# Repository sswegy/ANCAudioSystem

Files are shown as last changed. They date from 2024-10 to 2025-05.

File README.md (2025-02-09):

# ANCAudioSystem
## Автомобилна аудио система с активно шумопотискане - Дипломна работа

## Характеристики
- Активно шумопотискане
- Изравняване на звука по 3 честотни ленти
- Изравняване на противошума по 3 честотни ленти
- Bluetooth връзка
- AUX връзка
- Визуализация на метаданните на песните
- Контроли за промяна/пауза на песента

## Използвани технологии
- ESP32-WROOM-32
- C++
- Електроника

[Документация](https://docs.google.com/document/d/18OyuSNhzSNt5vsgb9MGb9Y_gkE6eRHnCl0IYLaxOIx8/edit?usp=sharing)

## Автор
[Виктор Велков](https://www.github.com/sswegy) 

Произведено во Света Троица

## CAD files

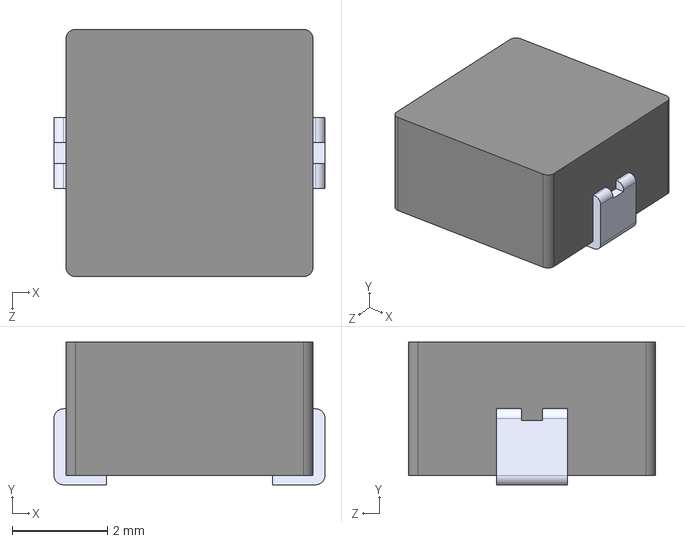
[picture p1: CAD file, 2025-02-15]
Electronics/KiCad_SnF_Library/3DModels/SRP5030T-1R0M.step
5.70 x 3.00 x 5.20 mm

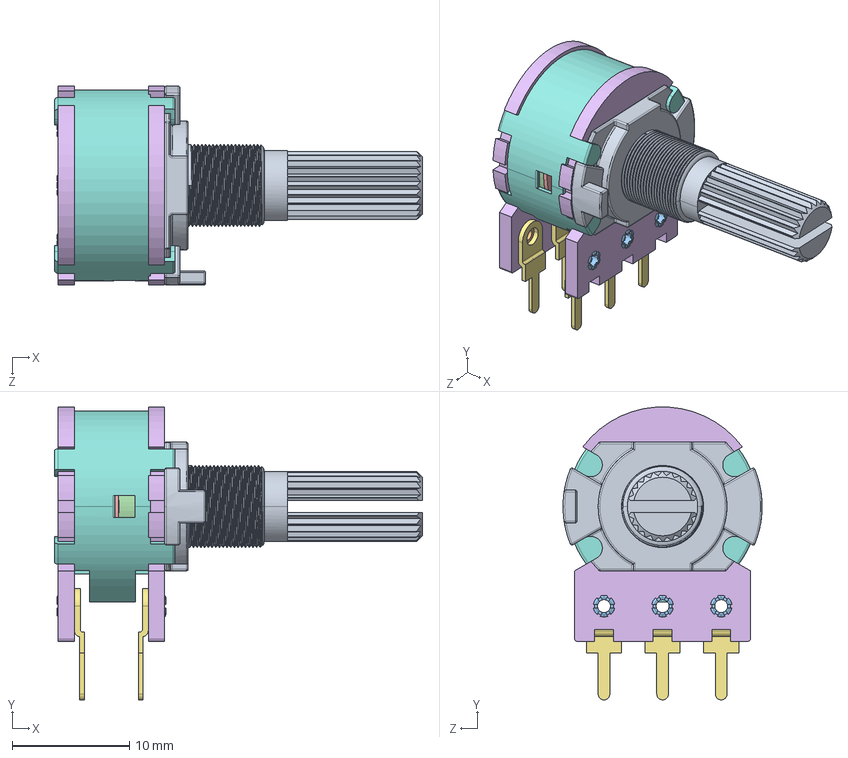
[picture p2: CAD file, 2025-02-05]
Electronics/KiCad_SnF_Library/3DModels/OtherPotentiometer.step
31.4 x 25.0 x 17.0 mm
PTN16_2 BUSHING
PTN16-A_2 HOUSING
PTN16_20K1_SHAFT

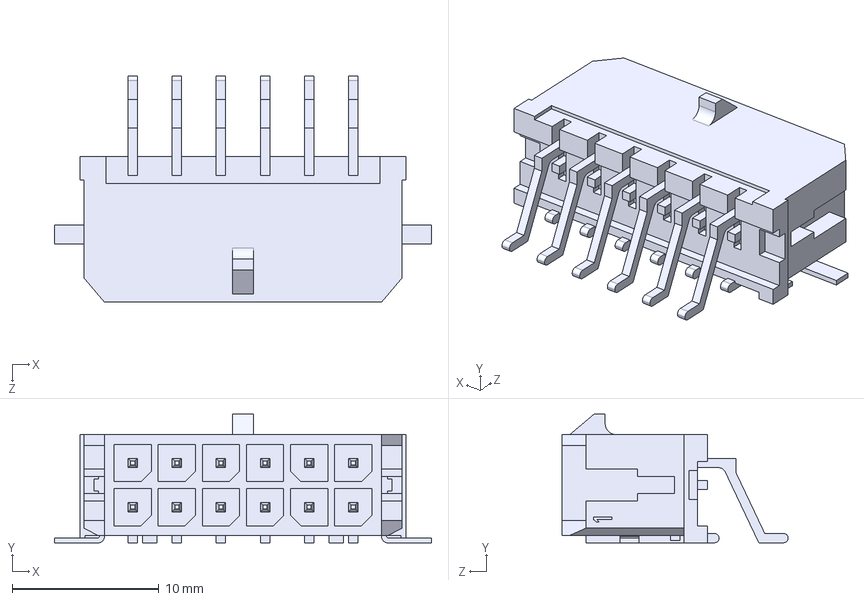
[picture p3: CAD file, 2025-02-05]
Electronics/KiCad_SnF_Library/3DModels/Molex-43045-1211.STEP
25.6 x 8.77 x 15.4 mm

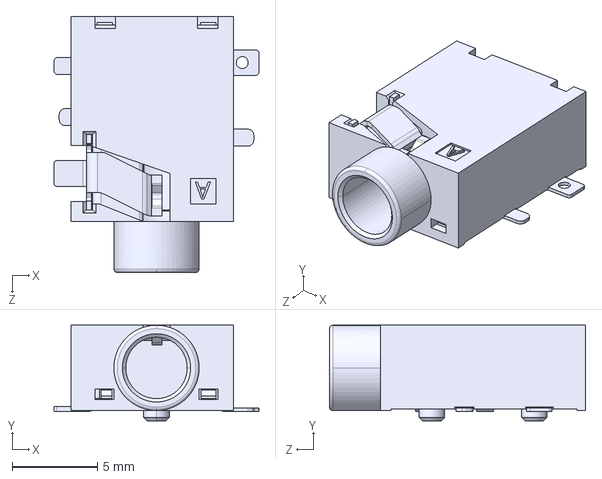
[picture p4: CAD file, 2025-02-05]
Electronics/KiCad_SnF_Library/3DModels/SJ1-3515-SMT-TR-BE.STEP
12.0 x 5.60 x 15.0 mm

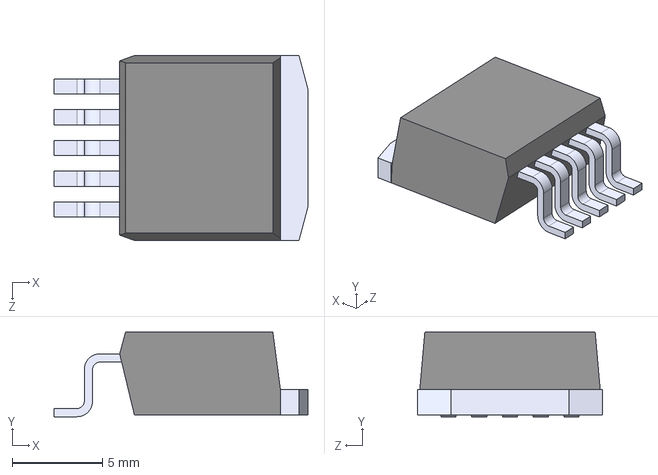
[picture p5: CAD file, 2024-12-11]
Electronics/KiCad_SnF_Library/3DModels/LT3015EQ-5PBF.step
14.0 x 4.67 x 10.2 mm

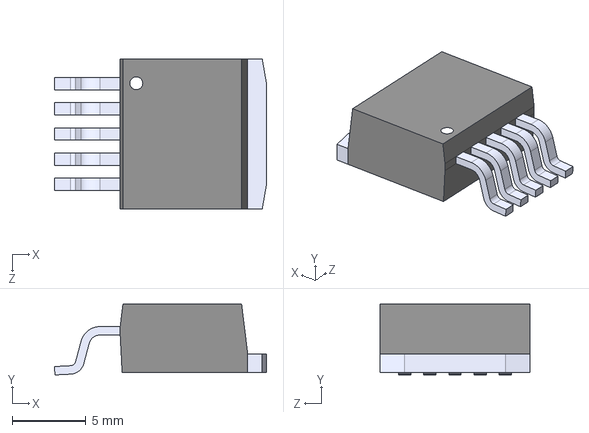
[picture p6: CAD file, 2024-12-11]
Electronics/KiCad_SnF_Library/3DModels/LP3856ES-5.0.step
14.4 x 4.80 x 10.2 mm

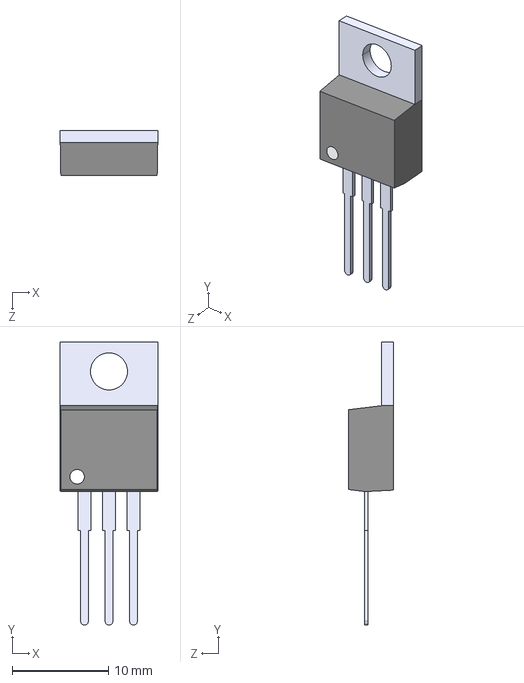
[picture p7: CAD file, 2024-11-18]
Electronics/KiCad_SnF_Library/3DModels/LM1085IT-3.3.step
10.2 x 29.3 x 4.70 mm

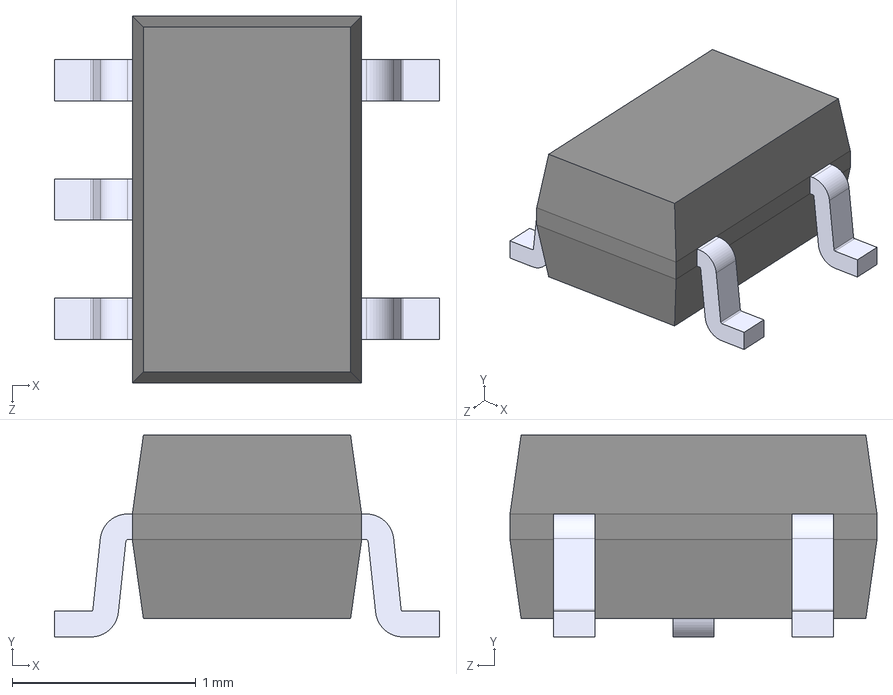
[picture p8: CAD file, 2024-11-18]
Electronics/KiCad_SnF_Library/3DModels/MIC5365-1.2YC5-TR.step
2.10 x 1.10 x 2.00 mm

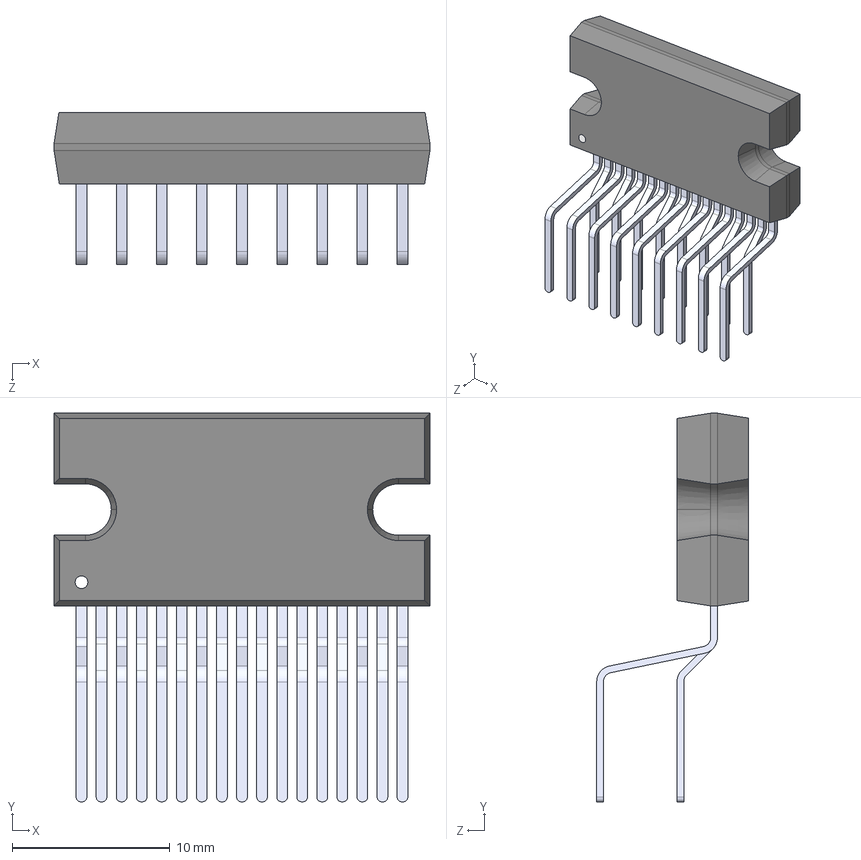
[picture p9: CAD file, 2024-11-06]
Electronics/KiCad_SnF_Library/3DModels/TDA1558Q.step
23.8 x 24.6 x 9.59 mm

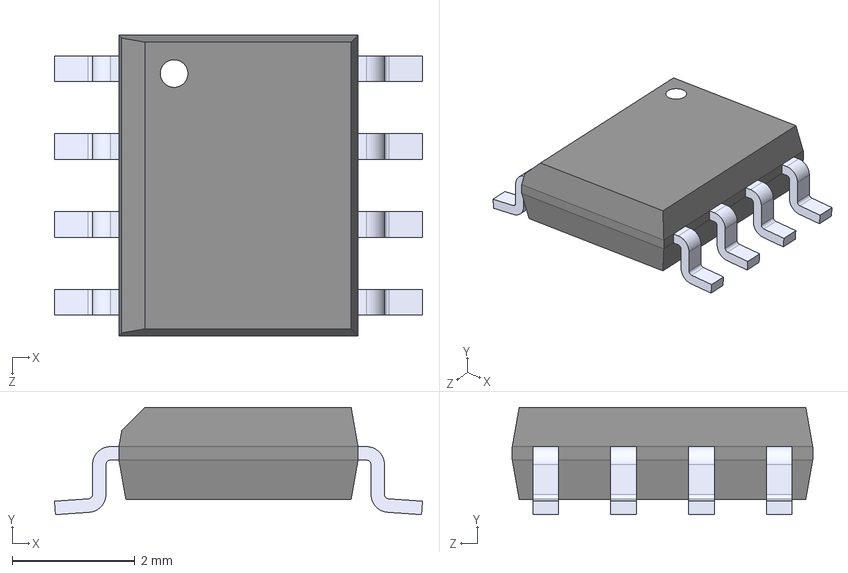
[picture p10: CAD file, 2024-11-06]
Electronics/KiCad_SnF_Library/3DModels/MAX660ESA.step
6.00 x 1.75 x 4.90 mm

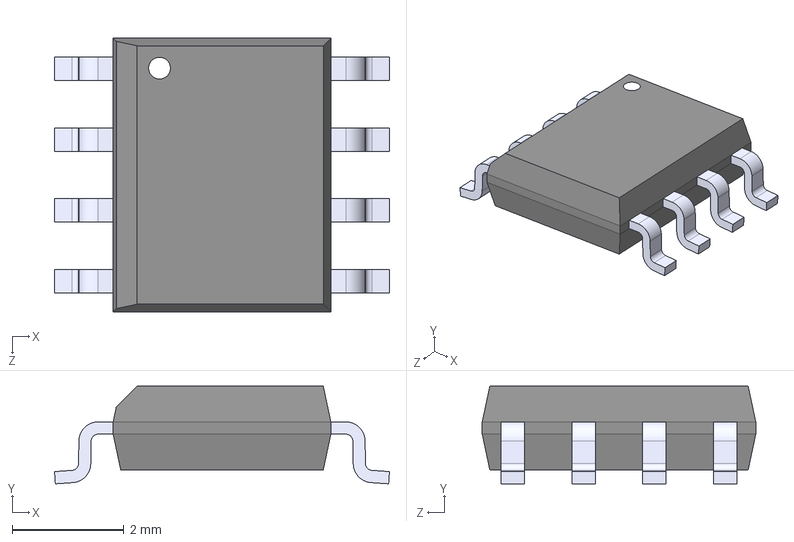
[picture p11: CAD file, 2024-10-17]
Electronics/KiCad_SnF_Library/3DModels/OPA2134UA.step
6.00 x 1.75 x 4.90 mm

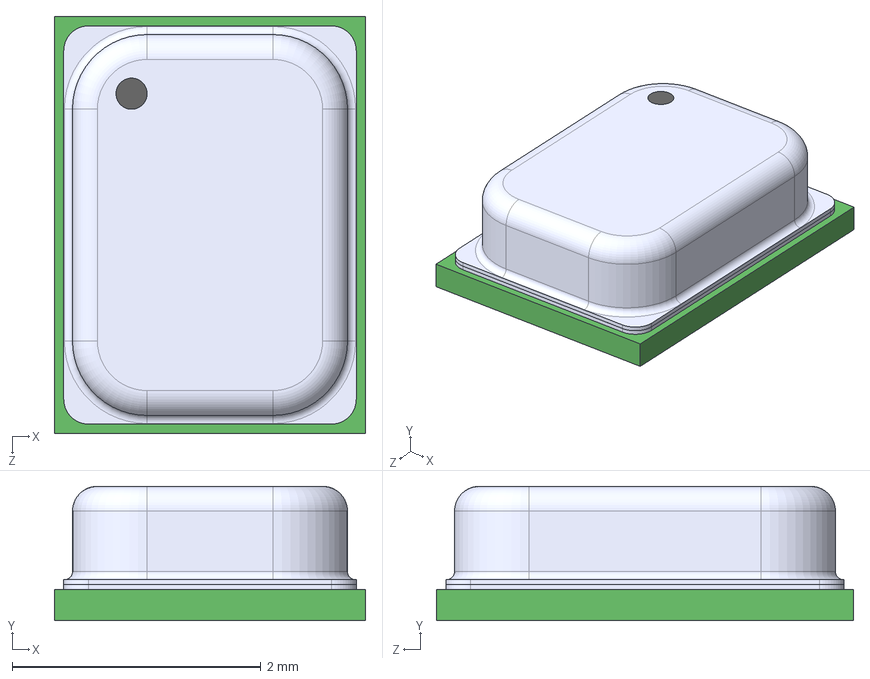
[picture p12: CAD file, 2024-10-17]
Electronics/KiCad_SnF_Library/3DModels/ICS-40310.step
2.50 x 1.08 x 3.35 mm

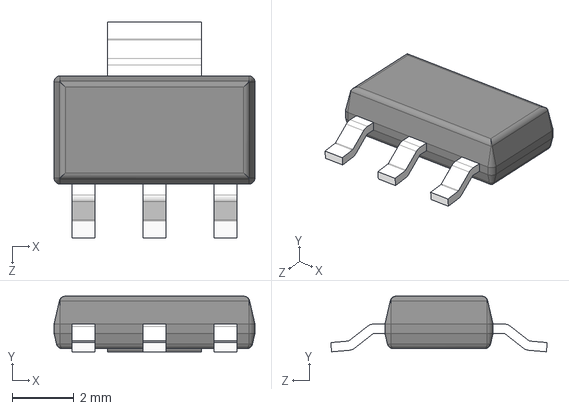
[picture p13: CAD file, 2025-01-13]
Electronics/KiCad_SnF_Library/3DModels/MIC39100-5.0WS.step
6.50 x 1.80 x 7.00 mm

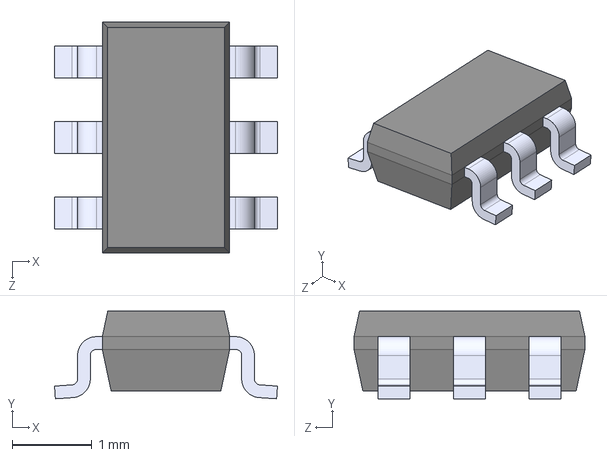
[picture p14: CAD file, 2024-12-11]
Electronics/KiCad_SnF_Library/3DModels/LMR51420XFDDCR.step
2.80 x 1.10 x 2.90 mm

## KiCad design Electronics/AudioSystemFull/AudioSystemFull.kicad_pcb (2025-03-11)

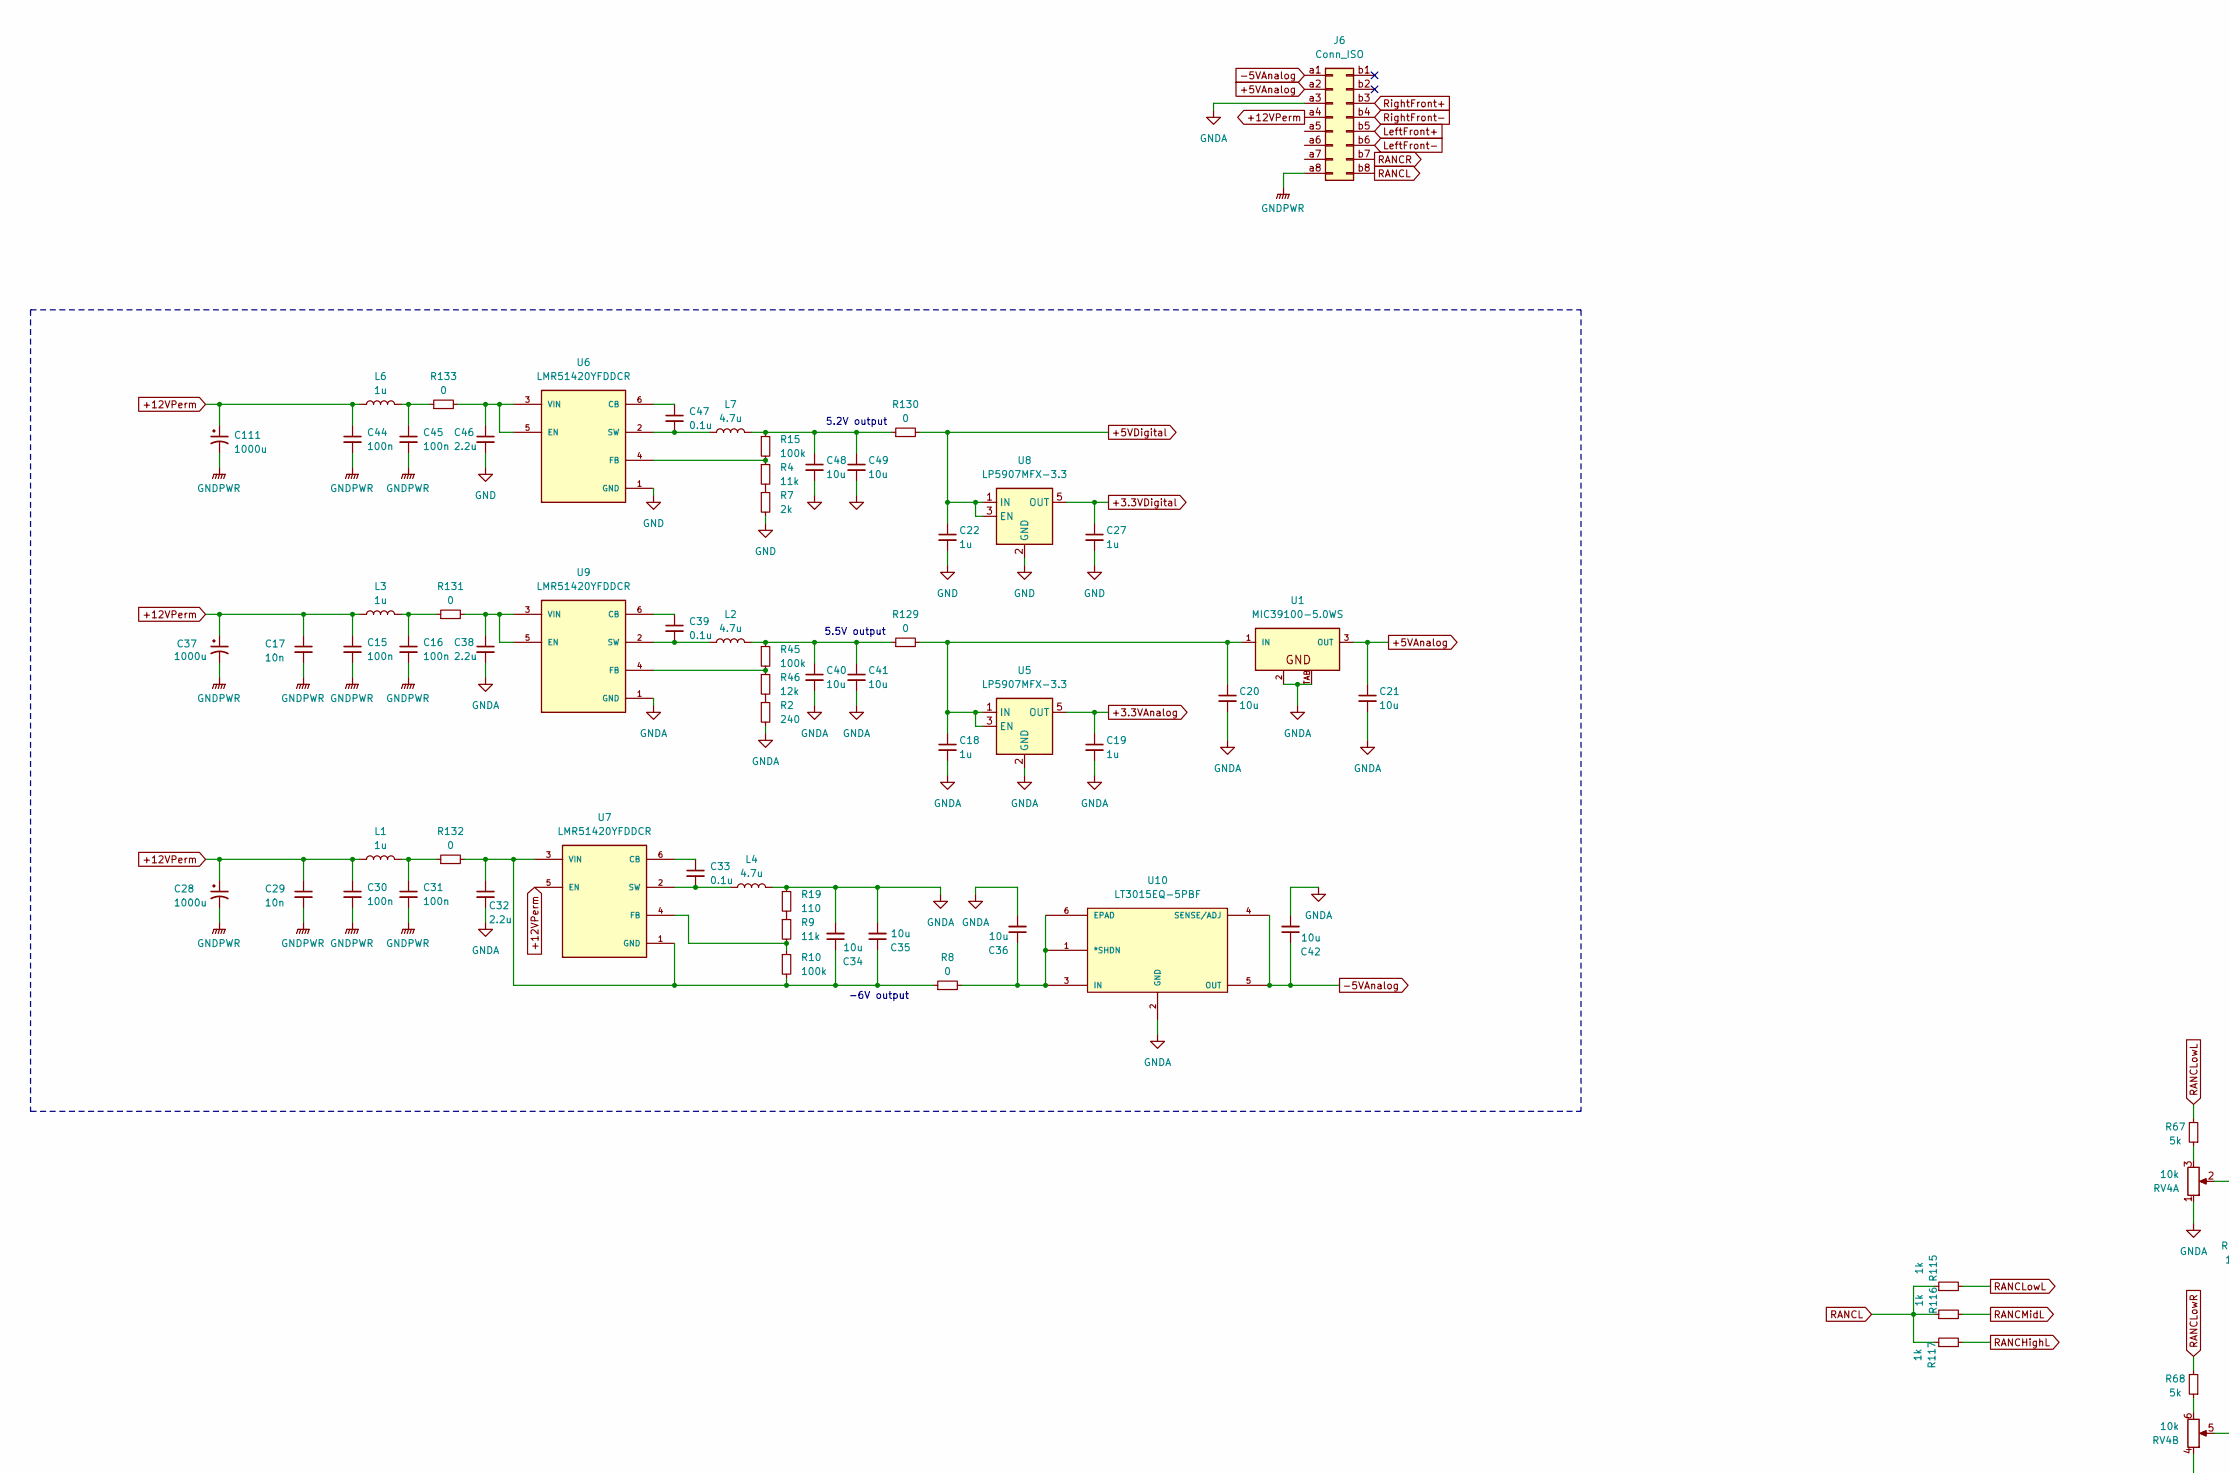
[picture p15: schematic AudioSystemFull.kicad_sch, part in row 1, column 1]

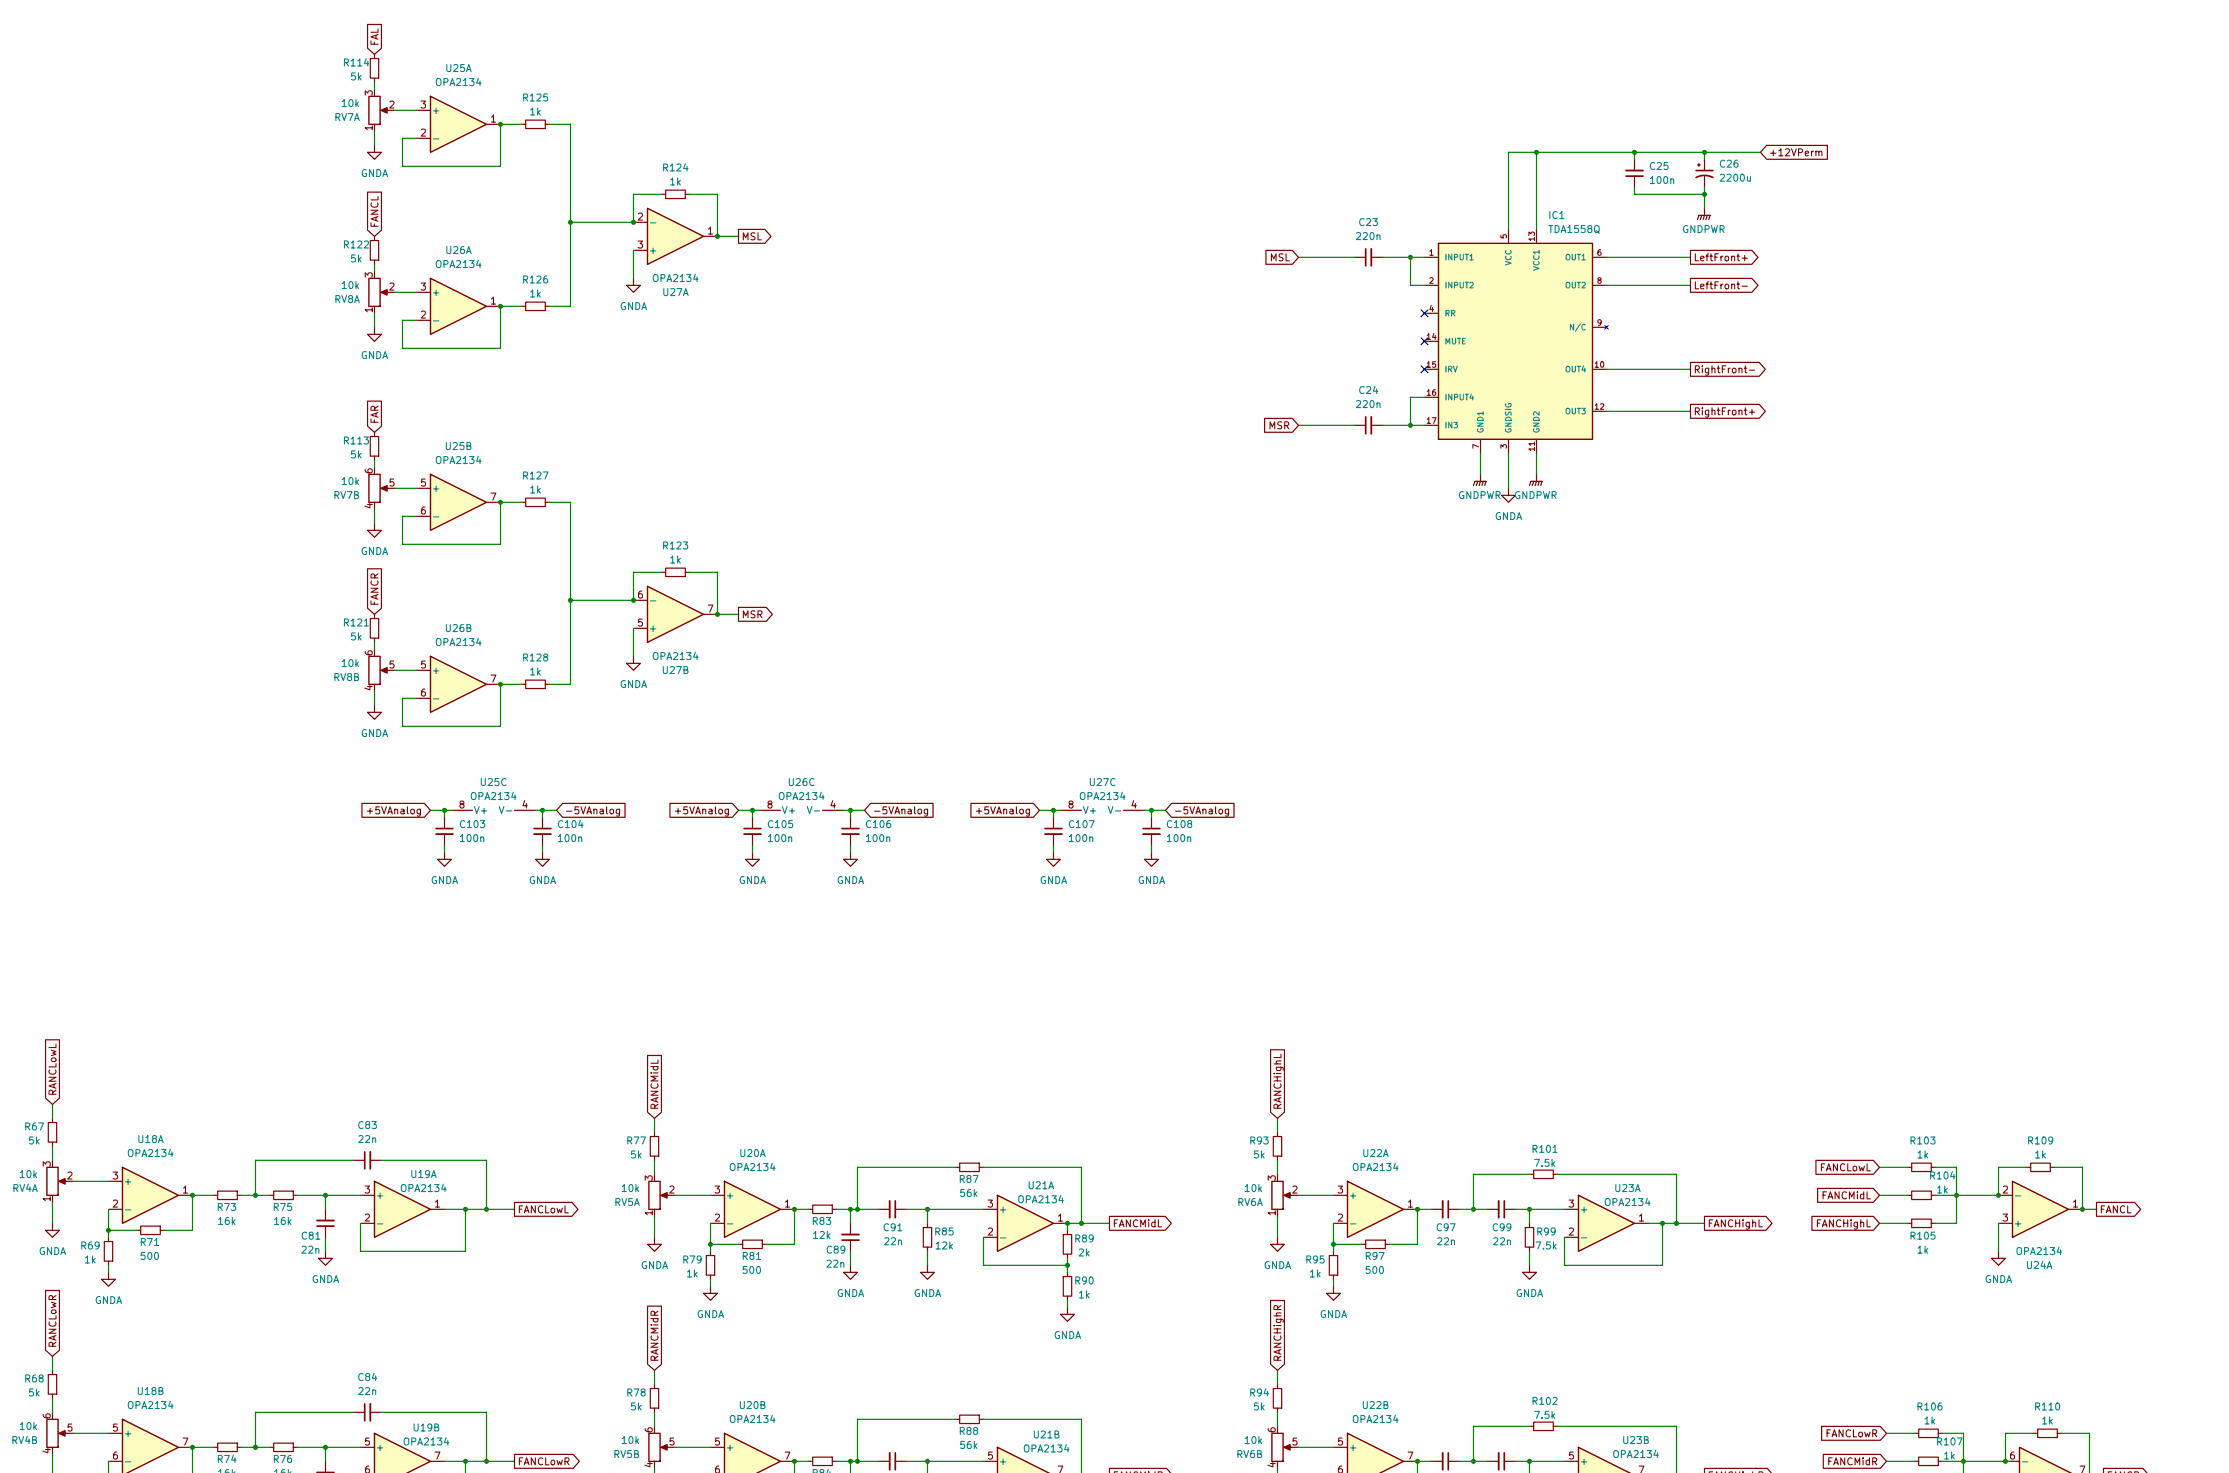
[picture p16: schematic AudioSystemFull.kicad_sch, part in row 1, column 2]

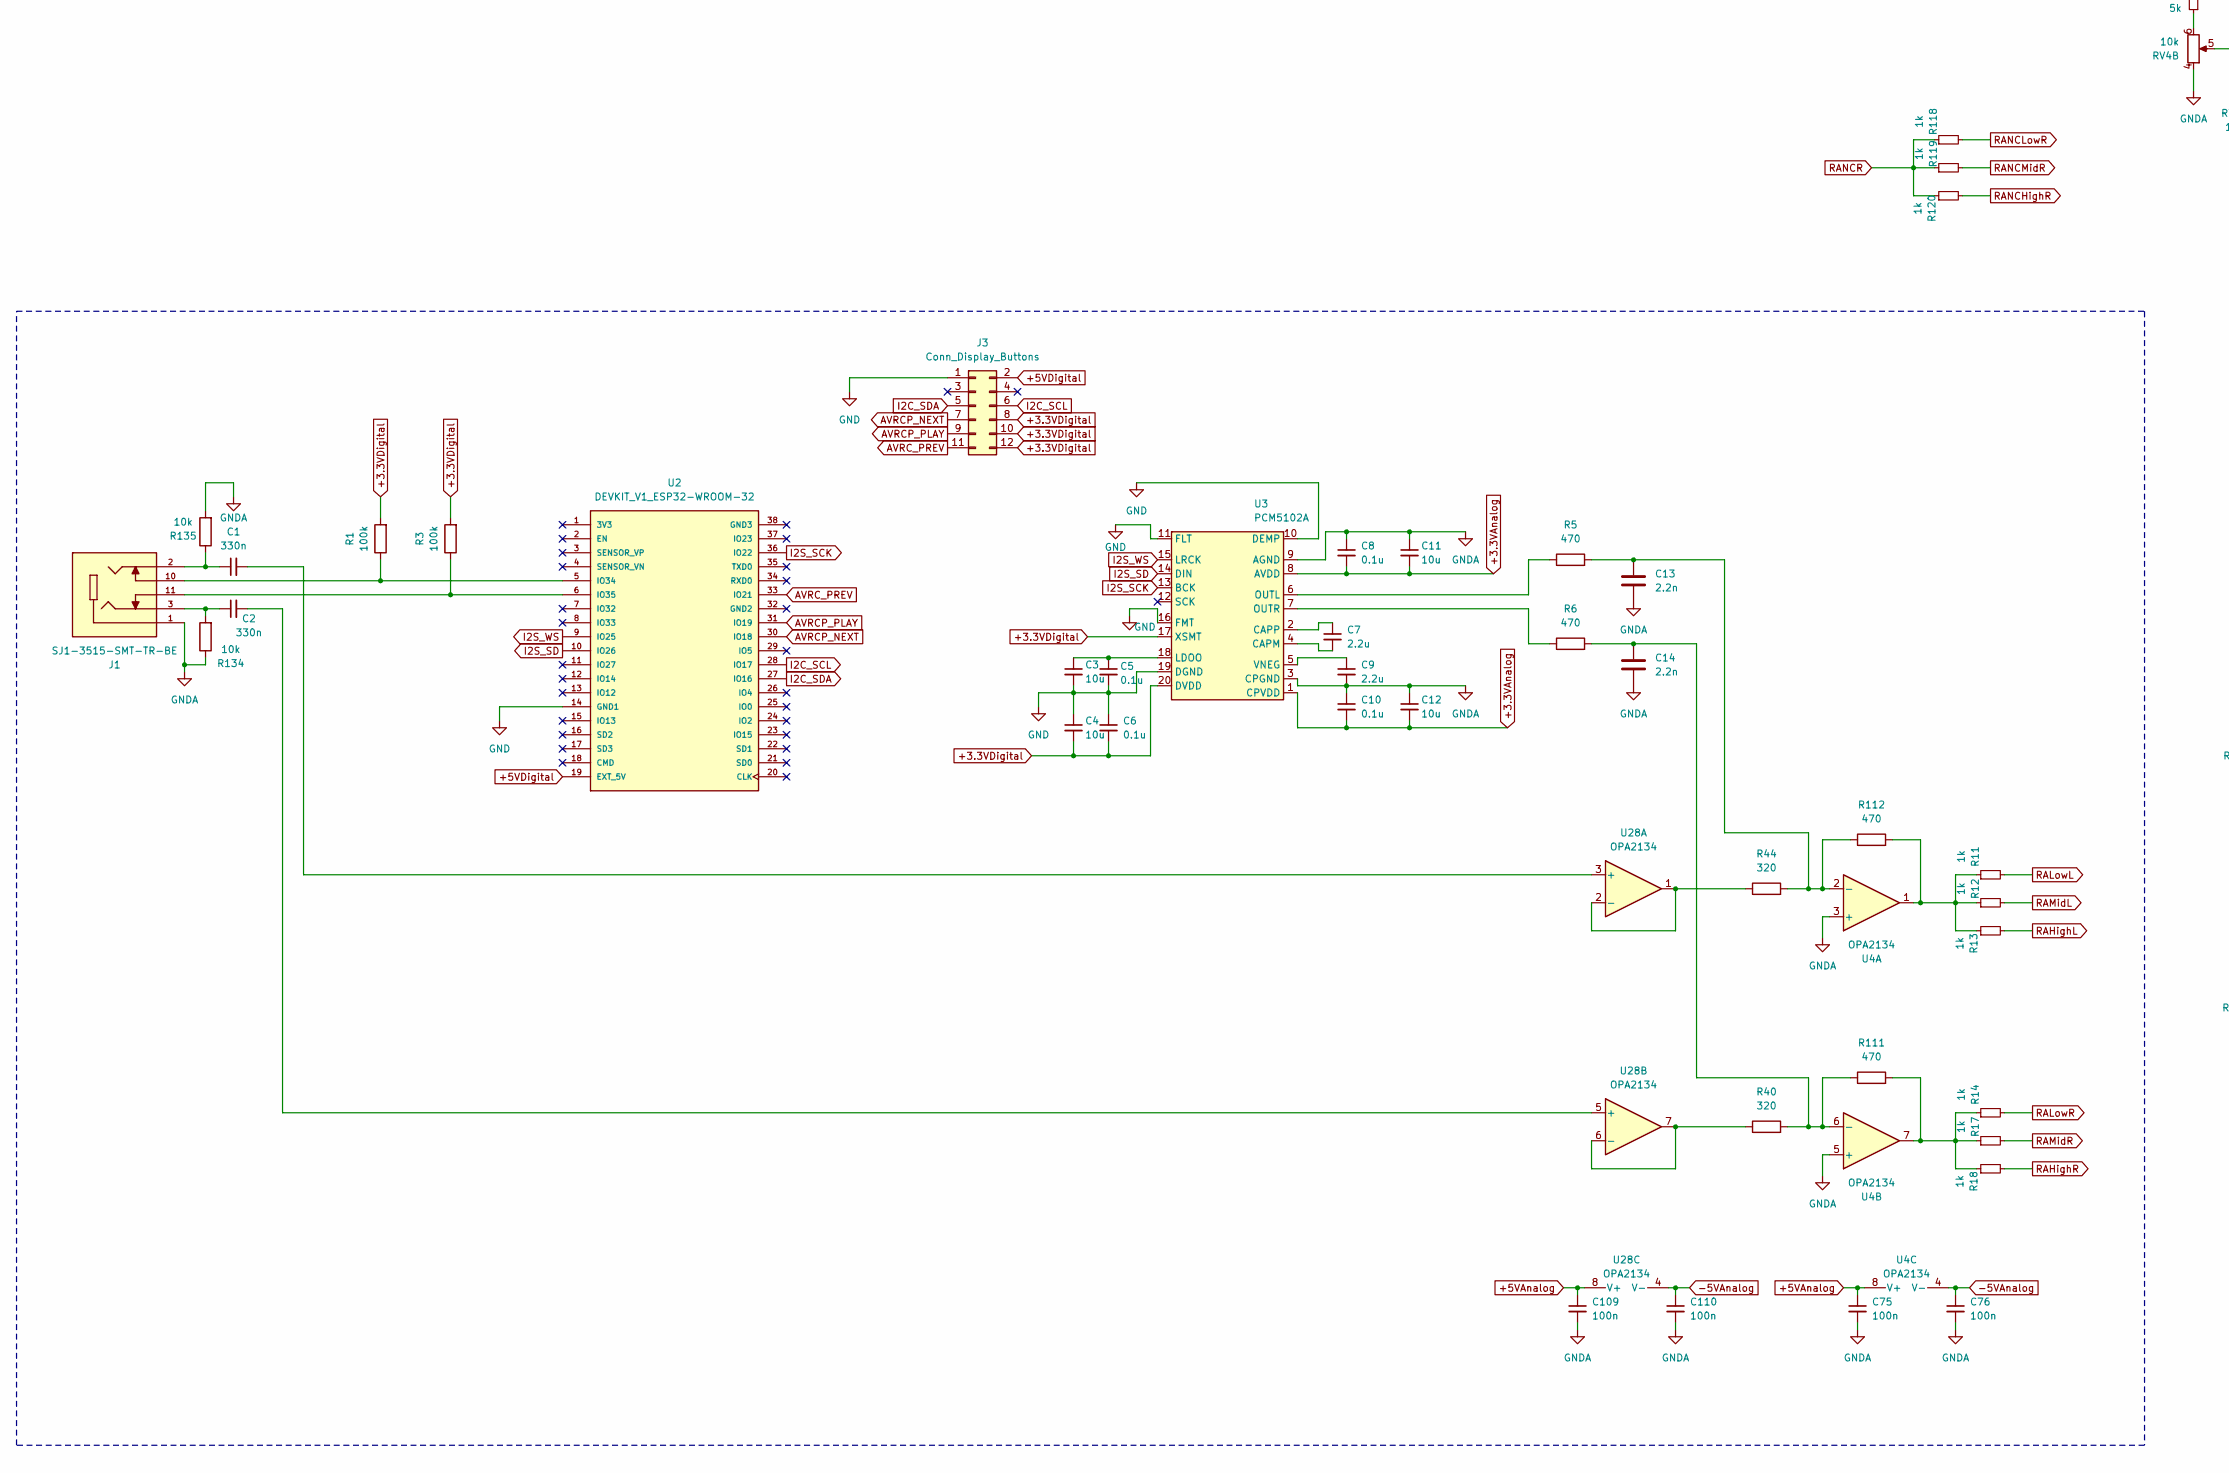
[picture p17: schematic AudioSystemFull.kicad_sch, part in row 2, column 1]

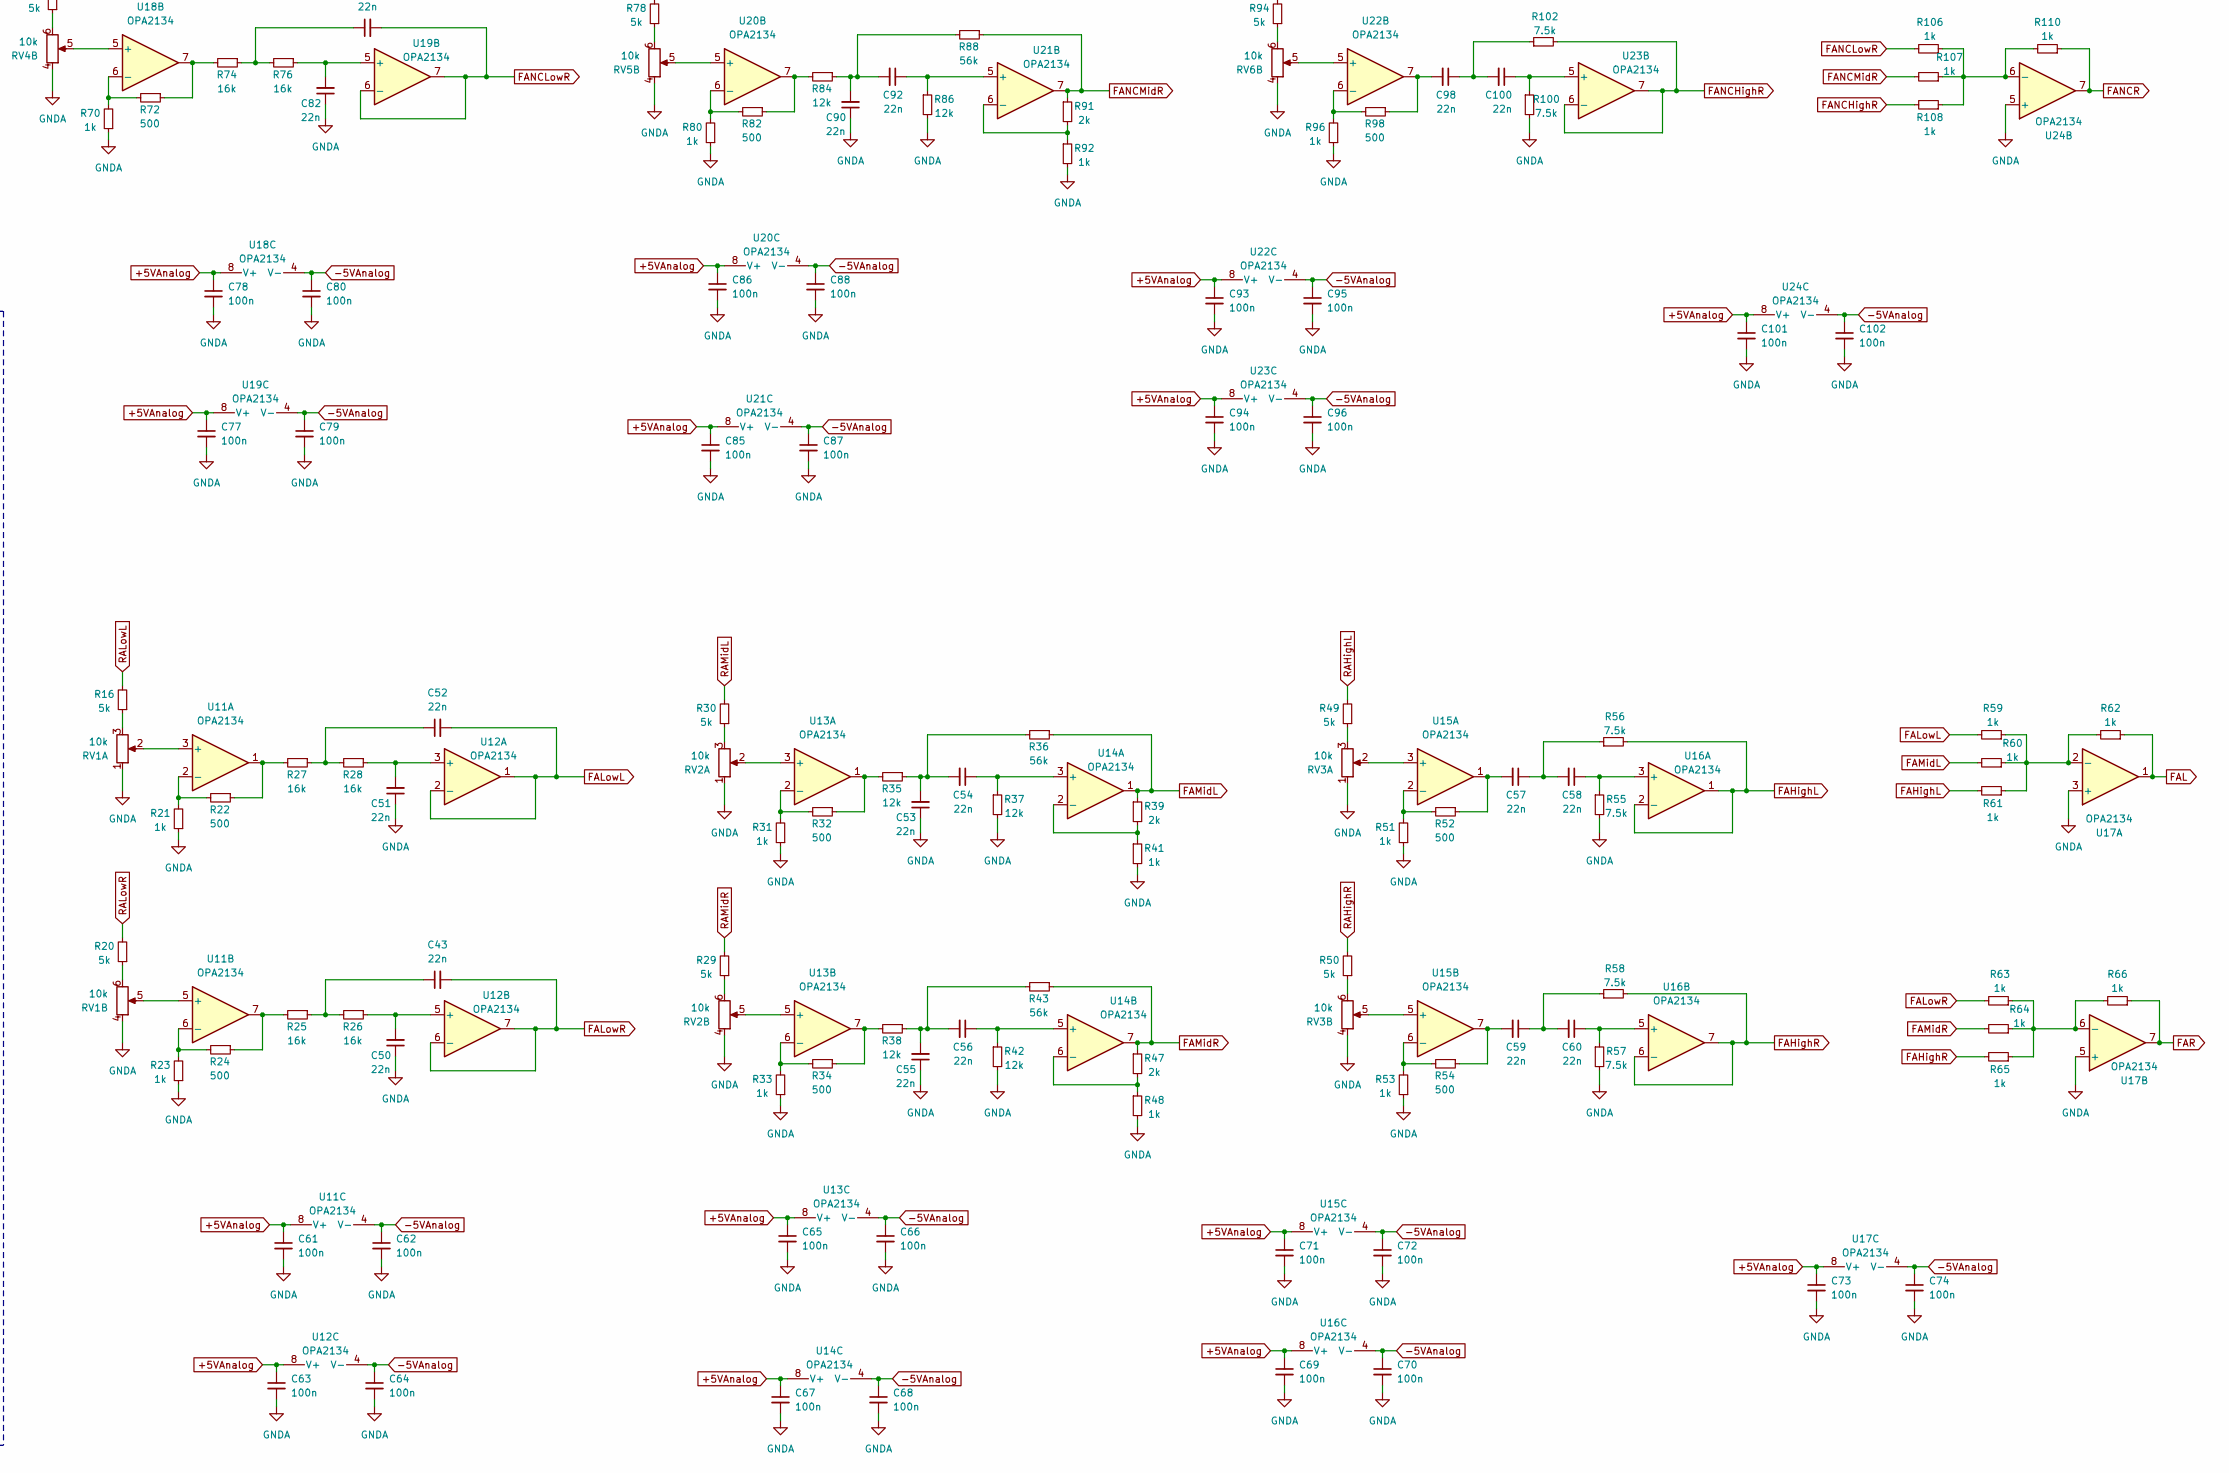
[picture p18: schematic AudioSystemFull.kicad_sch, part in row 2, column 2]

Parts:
C1, C2: 330n; C_1206_3216Metric_Pad1.33x1.80mm_HandSolder; MANUFACTURER_PART_NUMBER GRM31C5C1E334JE01L
C3, C4, C11, C12, C20, C21, C34, C35, C36, C40, C41, C42, C48, C49: 10u; C_0805_2012Metric_Pad1.18x1.45mm_HandSolder; MANUFACTURER_PART_NUMBER GRM21BZ71E106KE15K
C5, C6, C8, C10, C33, C39, C47: 0.1u; C_0805_2012Metric_Pad1.18x1.45mm_HandSolder; MANUFACTURER_PART_NUMBER C0805C104K3RACTU
C7, C9, C32, C38, C46: 2.2u; C_0805_2012Metric_Pad1.18x1.45mm_HandSolder; MANUFACTURER_PART_NUMBER CC0805KKX7R9BB225
C13, C14: 2.2n; C_0805_2012Metric_Pad1.18x1.45mm_HandSolder; MANUFACTURER_PART_NUMBER C0805C222J5GACTU
C15, C16, C25, C30, C31, C44, C45, C61, C62, C63, C64, C65, C66, C67, C68, C69, C70, C71, C72, C73, C74, C75, C76, C77, C78, C79, C80, C85, C86, C87, C88, C93, C94, C95, C96, C101, C102, C103, C104, C105, C106, C107, C108, C109, C110: 100n; C_0805_2012Metric_Pad1.18x1.45mm_HandSolder; MANUFACTURER_PART_NUMBER C0805C104K3RACTU
C17, C29: 10n; C_0805_2012Metric_Pad1.18x1.45mm_HandSolder; MANUFACTURER_PART_NUMBER C0805C103K1RACTU
C18, C19, C22, C27: 1u; C_0805_2012Metric_Pad1.18x1.45mm_HandSolder; MANUFACTURER_PART_NUMBER C0805C105K3RACTU
C23, C24: 220n; C_1206_3216Metric_Pad1.33x1.80mm_HandSolder; MANUFACTURER_PART_NUMBER GRM31C5C1E224JE02L
C26: 2200u; CP_Radial_D12.5mm_P5.00mm; MANUFACTURER_PART_NUMBER EGPD350ELL222MK30H
C28, C37, C111: 1000u; CP_Radial_D12.5mm_P5.00mm; MANUFACTURER_PART_NUMBER UKT1V102MHD1TO
C43, C50, C51, C52, C53, C54, C55, C56, C57, C58, C59, C60, C81, C82, C83, C84, C89, C90, C91, C92, C97, C98, C99, C100: 22n; C_0805_2012Metric_Pad1.18x1.45mm_HandSolder; MANUFACTURER_PART_NUMBER C0805C223K5GEC7210
IC1: TDA1558Q; MANUFACTURER_PART_NUMBER TDA1558Q
J1: SJ1-3515-SMT-TR-BE; PARTREV 1.08
J3: Conn_Display_Buttons; Molex-43045-1211; MANUFACTURER_PART_NUMBER Molex-43045-1211
J6: Conn_ISO; Conn_ISO_Solder_Pad
L1, L3, L6: 1u; SRP5030T-1R0M; MANUFACTURER_PART_NUMBER SRP5030T-1R0M
L2, L4, L7: 4.7u; VLS6045EX-4R7M-H; MANUFACTURER_PART_NUMBER VLS6045EX-4R7M-H
R1, R3, R10, R15, R45: 100k; R_0805_2012Metric_Pad1.20x1.40mm_HandSolder; MANUFACTURER_PART_NUMBER RT0805FRE10100KL
R2: 240; R_0805_2012Metric_Pad1.20x1.40mm_HandSolder; MANUFACTURER_PART_NUMBER RT0805FRE07240RL
R4, R9: 11k; R_0805_2012Metric_Pad1.20x1.40mm_HandSolder; MANUFACTURER_PART_NUMBER RT0805FRE0711KL
R5, R6, R111, R112: 470; R_0805_2012Metric_Pad1.20x1.40mm_HandSolder; MANUFACTURER_PART_NUMBER RT0805DRD07470RL
R7, R39, R47, R89, R91: 2k; R_0805_2012Metric_Pad1.20x1.40mm_HandSolder; MANUFACTURER_PART_NUMBER RT0805FRE102KL
R8, R129, R130, R131, R132, R133: 0; R_0805_2012Metric_Pad1.20x1.40mm_HandSolder; MANUFACTURER_PART_NUMBER PT0805-R-070RL
R11, R12, R13, R14, R17, R18, R21, R23, R31, R33, R41, R48, R51, R53, R59, R60, R61, R62, R63, R64, R65, R66, R69, R70, R79, R80, R90, R92, R95, R96, R103, R104, R105, R106, R107, R108, R109, R110, R115, R116, R117, R118, R119, R120, R123, R124, R125, R126, R127, R128: 1k; R_0805_2012Metric_Pad1.20x1.40mm_HandSolder; MANUFACTURER_PART_NUMBER RT0805FRE071KL
R16, R20, R29, R30, R49, R50, R67, R68, R77, R78, R93, R94, R113, R114, R121, R122: 5k; R_0805_2012Metric_Pad1.20x1.40mm_HandSolder; MANUFACTURER_PART_NUMBER CRT0805-BY-5001EAS
R19: 110; R_0805_2012Metric_Pad1.20x1.40mm_HandSolder; MANUFACTURER_PART_NUMBER RT0805FRE07110RL
R22, R24, R32, R34, R52, R54, R71, R72, R81, R82, R97, R98: 500; R_0805_2012Metric_Pad1.20x1.40mm_HandSolder; MANUFACTURER_PART_NUMBER RN73R2ATTD5000B25
R25, R26, R27, R28, R73, R74, R75, R76: 16k; R_0805_2012Metric_Pad1.20x1.40mm_HandSolder; MANUFACTURER_PART_NUMBER RT0805FRE0716KL
R35, R37, R38, R42, R46, R83, R84, R85, R86: 12k; R_0805_2012Metric_Pad1.20x1.40mm_HandSolder; MANUFACTURER_PART_NUMBER RT0805FRE0712KL
R36, R43, R87, R88: 56k; R_0805_2012Metric_Pad1.20x1.40mm_HandSolder; MANUFACTURER_PART_NUMBER RT0805DRE0756KL
R40, R44: 320; R_0805_2012Metric_Pad1.20x1.40mm_HandSolder; MANUFACTURER_PART_NUMBER RT0805BRD07320RL
R55, R56, R57, R58, R99, R100, R101, R102: 7.5k; R_0805_2012Metric_Pad1.20x1.40mm_HandSolder; MANUFACTURER_PART_NUMBER RT0805FRE077K5L
R134, R135: 10k; R_0805_2012Metric_Pad1.20x1.40mm_HandSolder; MANUFACTURER_PART_NUMBER RT0805FRE1310KL
RV1, RV2, RV3, RV4, RV5, RV6, RV7, RV8: 10k; PTN092H10120K1B; MANUFACTURER_PART_NUMBER PTN092H10120K1B
U1: MIC39100-5.0WS; MANUFACTURER_PART_NUMBER MIC39100-5.0WS-TR
U2: DEVKIT_V1_ESP32-WROOM-32; MODULE_DEVKIT_V1_ESP32-WROOM-32; PARTREV N/A
U3: PCM5102A; TSSOP-20_4.4x6.5mm_P0.65mm; MANUFACTURER_PART_NUMBER PCM5102A
U4, U11, U12, U13, U14, U15, U16, U17, U18, U19, U20, U21, U22, U23, U24, U25, U26, U27, U28: OPA2134; OPA2134UA; MANUFACTURER_PART_NUMBER OPA2134UA
U5, U8: LP5907MFX-3.3; SOT-23-5; MANUFACTURER_PART_NUMBER LP5907MFX-3.3
U6, U7, U9: LMR51420YFDDCR; PARTREV C
U10: LT3015EQ-5PBF; MANUFACTURER_PART_NUMBER LT3015EQ-5PBF

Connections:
+3.3VAnalog: C8.2, C10.2, C11.2, C12.2, C19.1, U3.1 (CPVDD), U3.8 (AVDD), U5.5 (OUT)
+3.3VDigital: C4.2, C6.2, C27.1, J3.8, J3.10, J3.12, R1.2, R3.2, U3.17 (XSMT), U3.20 (DVDD), U8.5 (OUT)
+5VAnalog: C21.1, C61.1, C63.1, C65.1, C67.1, C69.1, C71.1, C73.1, C75.1, C77.1, C78.1, C85.1, C86.1, C93.1, C94.1, C101.1, C103.1, C105.1, C107.1, C109.1, J6.a2, U1.3 (OUT), U4.8 (V+), U11.8 (V+), U12.8 (V+), U13.8 (V+), U14.8 (V+), U15.8 (V+), U16.8 (V+), U17.8 (V+), U18.8 (V+), U19.8 (V+), U20.8 (V+), U21.8 (V+), U22.8 (V+), U23.8 (V+), U24.8 (V+), U25.8 (V+), U26.8 (V+), U27.8 (V+), U28.8 (V+)
+5VDigital: C22.1, J3.2, R130.2, U2.19 (EXT_5V), U8.1 (IN), U8.3 (EN)
+12VPerm: C15.1, C17.1, C25.2, C26.1, C28.1, C29.1, C30.1, C37.1, C44.1, C111.1, IC1.5 (VCC), IC1.13 (VCC1), J6.a4, L1.1, L3.1, L6.1, U7.5 (EN)
-5VAnalog: C42.1, C62.1, C64.1, C66.1, C68.1, C70.1, C72.1, C74.1, C76.1, C79.1, C80.1, C87.1, C88.1, C95.1, C96.1, C102.1, C104.1, C106.1, C108.1, C110.1, J6.a1, U4.4 (V-), U10.4 (SENSE/ADJ), U10.5 (OUT), U11.4 (V-), U12.4 (V-), U13.4 (V-), U14.4 (V-), U15.4 (V-), U16.4 (V-), U17.4 (V-), U18.4 (V-), U19.4 (V-), U20.4 (V-), U21.4 (V-), U22.4 (V-), U23.4 (V-), U24.4 (V-), U25.4 (V-), U26.4 (V-), U27.4 (V-), U28.4 (V-)
AVRCP_NEXT: J3.7, U2.30 (IO18)
AVRCP_PLAY: J3.9, U2.31 (IO19)
AVRC_PREV: J3.11, U2.33 (IO21)
FAHighL: R56.2, R61.2, U16.1, U16.2 (-)
FAHighR: R58.2, R65.2, U16.6 (-), U16.7
FAL: R62.1, R114.2, U17.1
FALowL: C52.2, R59.2, U12.1, U12.2 (-)
FALowR: C43.2, R63.2, U12.6 (-), U12.7
FAMidL: R36.1, R39.1, R60.2, U14.1
FAMidR: R43.1, R47.1, R64.2, U14.7
FANCHighL: R101.2, R105.2, U23.1, U23.2 (-)
FANCHighR: R102.2, R108.2, U23.6 (-), U23.7
FANCL: R109.1, R122.2, U24.1
FANCLowL: C83.2, R103.2, U19.1, U19.2 (-)
FANCLowR: C84.2, R106.2, U19.6 (-), U19.7
FANCMidL: R87.1, R89.1, R104.2, U21.1
FANCMidR: R88.1, R91.1, R107.2, U21.7
FANCR: R110.1, R121.2, U24.7
FAR: R66.1, R113.2, U17.7
GND: C3.2, C4.1, C5.2, C6.1, C22.2, C27.2, C46.2, C48.2, C49.2, J3.1, R7.2, U2.14 (GND1), U3.10 (DEMP), U3.11 (FLT), U3.16 (FMT), U3.19 (DGND), U6.1 (GND), U8.2 (GND), U8.4 (NC)
GNDA: C8.1, C9.2, C10.1, C11.1, C12.1, C13.2, C14.2, C18.2, C19.2, C20.2, C21.2, C32.2, C34.2, C35.2, C36.2, C38.2, C40.2, C41.2, C42.2, C50.1, C51.1, C53.1, C55.1, C61.2, C62.2, C63.2, C64.2, C65.2, C66.2, C67.2, C68.2, C69.2, C70.2, C71.2, C72.2, C73.2, C74.2, C75.2, C76.2, C77.2, C78.2, C79.2, C80.2, C81.1, C82.1, C85.2, C86.2, C87.2, C88.2, C89.1, C90.1, C93.2, C94.2, C95.2, C96.2, C101.2, C102.2, C103.2, C104.2, C105.2, C106.2, C107.2, C108.2, C109.2, C110.2, IC1.3 (GNDSIG), J1.1, J6.a3, L4.2, R2.2, R19.1, R21.1, R23.1, R31.1, R33.1, R37.2, R41.2, R42.2, R48.2, R51.1, R53.1, R55.2, R57.2, R69.1, R70.1, R79.1, R80.1, R85.2, R86.2, R90.2, R92.2, R95.1, R96.1, R99.2, R100.2, R134.1, R135.2, RV1.1, RV1.4, RV2.1, RV2.4, RV3.1, RV3.4, RV4.1, RV4.4, RV5.1, RV5.4, RV6.1, RV6.4, RV7.1, RV7.4, RV8.1, RV8.4, U1.2, U1.TAB, U3.3 (CPGND), U3.9 (AGND), U4.3 (+), U4.5 (+), U5.2 (GND), U5.4 (NC), U9.1 (GND), U10.2 (GND), U17.3 (+), U17.5 (+), U24.3 (+), U24.5 (+), U27.3 (+), U27.5 (+)
GNDPWR: C15.2, C16.2, C17.2, C25.1, C26.2, C28.2, C29.2, C30.2, C31.2, C37.2, C44.2, C45.2, C111.2, IC1.7 (GND1), IC1.11 (GND2), J6.a8
I2C_SCL: J3.6, U2.28 (IO17)
I2C_SDA: J3.5, U2.27 (IO16)
I2S_SCK: U2.36 (IO22), U3.13 (BCK)
I2S_SD: U2.10 (IO26), U3.14 (DIN)
I2S_WS: U2.9 (IO25), U3.15 (LRCK)
LeftFront+: IC1.6 (OUT1), J6.b5
LeftFront-: IC1.8 (OUT2), J6.b6
MSL: C23.1, R124.1, U27.1
MSR: C24.1, R123.1, U27.7
unnamed: C1.1, J1.2, R135.1
unnamed: C2.1, J1.3, R134.2
unnamed: C16.1, L3.2, R131.1
unnamed: C31.1, L1.2, R132.1
unnamed: C40.1, C41.1, L2.2, R45.1, R129.1
unnamed: C43.1, R25.1, R26.2
unnamed: C45.1, L6.2, R133.1
unnamed: C48.1, C49.1, L7.2, R15.1, R130.1
unnamed: C52.1, R27.1, R28.2
unnamed: C53.2, C54.2, R35.1, R36.2
unnamed: C55.2, C56.2, R38.1, R43.2
unnamed: C57.1, C58.2, R56.1
unnamed: C57.2, R52.1, U15.1
unnamed: C59.1, C60.2, R58.1
unnamed: C59.2, R54.1, U15.7
unnamed: C83.1, R73.1, R75.2
unnamed: C84.1, R74.1, R76.2
unnamed: C89.2, C91.2, R83.1, R87.2
unnamed: C90.2, C92.2, R84.1, R88.2
unnamed: C97.1, C99.2, R101.1
unnamed: C97.2, R97.1, U22.1
unnamed: C98.2, R98.1, U22.7
unnamed: C98.1, C100.2, R102.1
unnamed: C24.2, IC1.16 (INPUT4), IC1.17 (IN3)
unnamed: C23.2, IC1.1 (INPUT1), IC1.2 (INPUT2)
unnamed: R2.1, R46.2
unnamed: R4.2, R7.1
unnamed: R11.1, R12.1, R13.1, R112.2, U4.1
unnamed: R16.1, RV1.3
unnamed: R9.1, R19.2
unnamed: R20.1, RV1.6
unnamed: R22.1, R27.2, U11.1
unnamed: R24.1, R25.2, U11.7
unnamed: R29.1, RV2.6
unnamed: R30.1, RV2.3
unnamed: R32.1, R35.2, U13.1
unnamed: R34.1, R38.2, U13.7
unnamed: R49.1, RV3.3
unnamed: R50.1, RV3.6
unnamed: R67.1, RV4.3
unnamed: R68.1, RV4.6
unnamed: R71.1, R73.2, U18.1
unnamed: R72.1, R74.2, U18.7
unnamed: R77.1, RV5.3
unnamed: R78.1, RV5.6
unnamed: R81.1, R83.2, U20.1
unnamed: R82.1, R84.2, U20.7
unnamed: R93.1, RV6.3
unnamed: R94.1, RV6.6
unnamed: R14.1, R17.1, R18.1, R111.2, U4.7
unnamed: R113.1, RV7.6
unnamed: R114.1, RV7.3
unnamed: R121.1, RV8.6
unnamed: R122.1, RV8.3
unnamed: C18.1, C20.1, R129.2, U1.1 (IN), U5.1 (IN), U5.3 (EN)
unnamed: J1.10, R1.1, U2.5 (IO34)
unnamed: J1.11, R3.1, U2.6 (IO35)
unnamed: C7.2, U3.4 (CAPM)
unnamed: C7.1, U3.2 (CAPP)
unnamed: C3.1, C5.1, U3.18 (LDOO)
unnamed: R5.1, U3.6 (OUTL)
unnamed: R6.1, U3.7 (OUTR)
unnamed: C9.1, U3.5 (VNEG)
unnamed: C13.1, R5.2, R44.2, R112.1, U4.2 (-)
unnamed: C14.1, R6.2, R40.2, R111.1, U4.6 (-)
unnamed: C47.1, U6.6 (CB)
unnamed: C46.1, R133.2, U6.3 (VIN), U6.5 (EN)
unnamed: R4.1, R15.2, U6.4 (FB)
unnamed: C47.2, L7.1, U6.2 (SW)
unnamed: C33.1, U7.6 (CB)
unnamed: R9.2, R10.1, U7.4 (FB)
unnamed: C32.1, C34.1, C35.1, R8.1, R10.2, R132.2, U7.1 (GND), U7.3 (VIN)
unnamed: C33.2, L4.1, U7.2 (SW)
unnamed: C39.1, U9.6 (CB)
unnamed: C38.1, R131.2, U9.3 (VIN), U9.5 (EN)
unnamed: R45.2, R46.1, U9.4 (FB)
unnamed: C39.2, L2.1, U9.2 (SW)
unnamed: C36.1, R8.2, U10.1 (*SHDN), U10.3 (IN), U10.6 (EPAD)
unnamed: RV1.2, U11.3 (+)
unnamed: R21.2, R22.2, U11.2 (-)
unnamed: RV1.5, U11.5 (+)
unnamed: R23.2, R24.2, U11.6 (-)
unnamed: C51.2, R28.1, U12.3 (+)
unnamed: C50.2, R26.1, U12.5 (+)
unnamed: RV2.2, U13.3 (+)
unnamed: R31.2, R32.2, U13.2 (-)
unnamed: RV2.5, U13.5 (+)
unnamed: R33.2, R34.2, U13.6 (-)
unnamed: C54.1, R37.1, U14.3 (+)
unnamed: R39.2, R41.1, U14.2 (-)
unnamed: C56.1, R42.1, U14.5 (+)
unnamed: R47.2, R48.1, U14.6 (-)
unnamed: RV3.2, U15.3 (+)
unnamed: R51.2, R52.2, U15.2 (-)
unnamed: RV3.5, U15.5 (+)
unnamed: R53.2, R54.2, U15.6 (-)
unnamed: C58.1, R55.1, U16.3 (+)
unnamed: C60.1, R57.1, U16.5 (+)
unnamed: R59.1, R60.1, R61.1, R62.2, U17.2 (-)
unnamed: R63.1, R64.1, R65.1, R66.2, U17.6 (-)
unnamed: RV4.2, U18.3 (+)
unnamed: R69.2, R71.2, U18.2 (-)
unnamed: RV4.5, U18.5 (+)
unnamed: R70.2, R72.2, U18.6 (-)
unnamed: C81.2, R75.1, U19.3 (+)
unnamed: C82.2, R76.1, U19.5 (+)
unnamed: RV5.2, U20.3 (+)
unnamed: R79.2, R81.2, U20.2 (-)
unnamed: RV5.5, U20.5 (+)
unnamed: R80.2, R82.2, U20.6 (-)
unnamed: C91.1, R85.1, U21.3 (+)
unnamed: R89.2, R90.1, U21.2 (-)
unnamed: C92.1, R86.1, U21.5 (+)
unnamed: R91.2, R92.1, U21.6 (-)
unnamed: RV6.2, U22.3 (+)
unnamed: R95.2, R97.2, U22.2 (-)
unnamed: RV6.5, U22.5 (+)
unnamed: R96.2, R98.2, U22.6 (-)
unnamed: C99.1, R99.1, U23.3 (+)
unnamed: C100.1, R100.1, U23.5 (+)
unnamed: R103.1, R104.1, R105.1, R109.2, U24.2 (-)
unnamed: R106.1, R107.1, R108.1, R110.2, U24.6 (-)
unnamed: RV7.2, U25.3 (+)
unnamed: R125.2, U25.1, U25.2 (-)
unnamed: RV7.5, U25.5 (+)
unnamed: R127.2, U25.6 (-), U25.7
unnamed: RV8.2, U26.3 (+)
unnamed: R126.2, U26.1, U26.2 (-)
unnamed: RV8.5, U26.5 (+)
unnamed: R128.2, U26.6 (-), U26.7
unnamed: R124.2, R125.1, R126.1, U27.2 (-)
unnamed: R123.2, R127.1, R128.1, U27.6 (-)
unnamed: C1.2, U28.3 (+)
unnamed: R44.1, U28.1, U28.2 (-)
unnamed: C2.2, U28.5 (+)
unnamed: R40.1, U28.6 (-), U28.7
RAHighL: R13.2, R49.2
RAHighR: R18.2, R50.2
RALowL: R11.2, R16.2
RALowR: R14.2, R20.2
RAMidL: R12.2, R30.2
RAMidR: R17.2, R29.2
RANCHighL: R93.2, R117.2
RANCHighR: R94.2, R120.2
RANCL: J6.b8, R115.1, R116.1, R117.1
RANCLowL: R67.2, R115.2
RANCLowR: R68.2, R118.2
RANCMidL: R77.2, R116.2
RANCMidR: R78.2, R119.2
RANCR: J6.b7, R118.1, R119.1, R120.1
RightFront+: IC1.12 (OUT3), J6.b3
RightFront-: IC1.10 (OUT4), J6.b4

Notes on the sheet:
5.2V output
-6V output
5.5V output

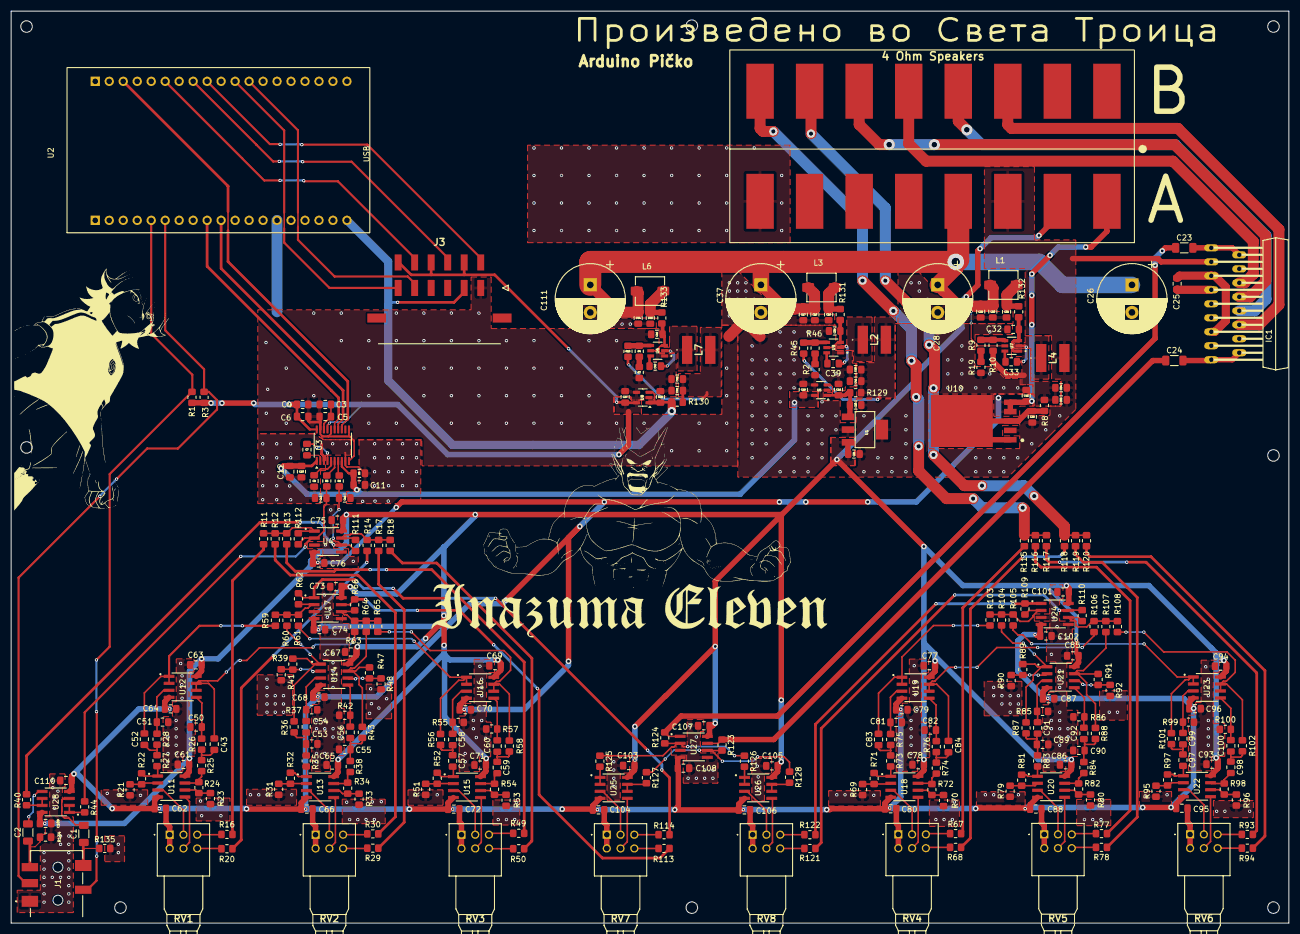
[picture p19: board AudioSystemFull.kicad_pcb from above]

Board: 2 copper layers, 232.1 x 165.7 mm, 292 parts (0 on the bottom side), 189 nets.

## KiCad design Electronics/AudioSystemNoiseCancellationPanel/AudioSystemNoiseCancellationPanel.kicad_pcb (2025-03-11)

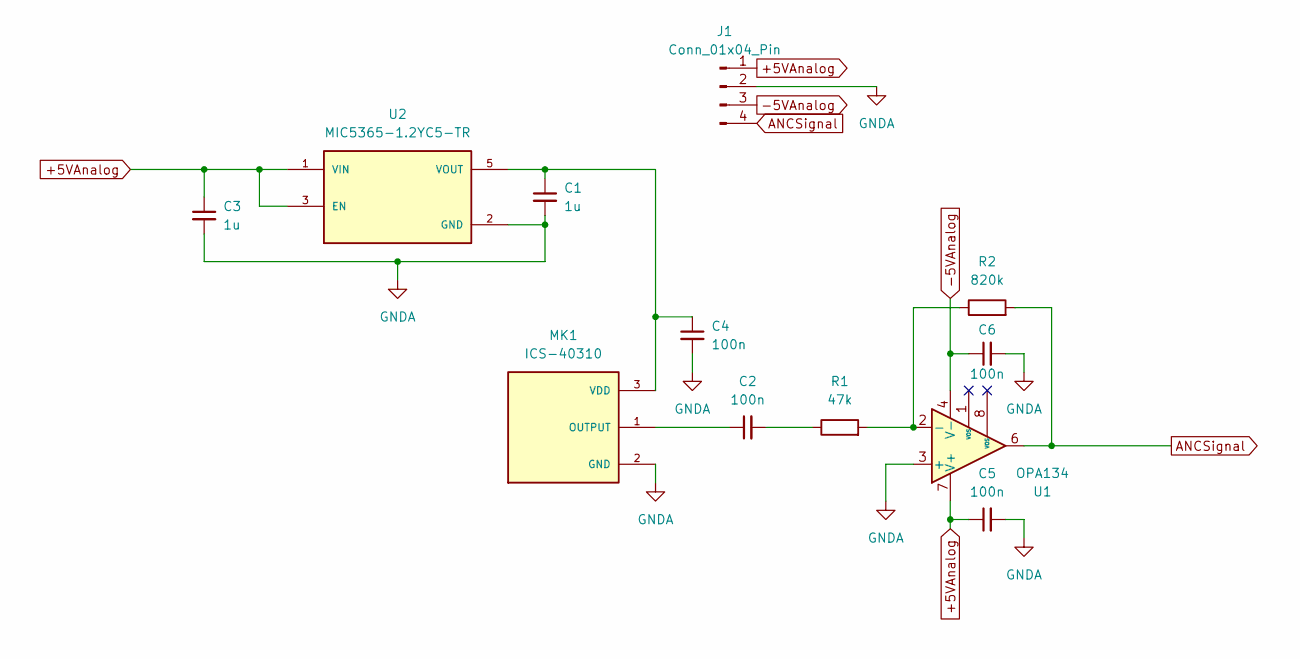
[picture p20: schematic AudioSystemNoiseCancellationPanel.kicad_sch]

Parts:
C1, C3: 1u; C_0805_2012Metric_Pad1.18x1.45mm_HandSolder
C2, C4, C5, C6: 100n; C_0805_2012Metric_Pad1.18x1.45mm_HandSolder
J1: Conn_01x04_Pin; 4_Pad_Connector
MK1: ICS-40310; MIC_ICS-40310; PARTREV 1.2
R1: 47k; R_0805_2012Metric_Pad1.20x1.40mm_HandSolder
R2: 820k; R_0805_2012Metric_Pad1.20x1.40mm_HandSolder
U1: OPA134; OPA134UA
U2: MIC5365-1.2YC5-TR; PARTREV 3.1 - July 16, 2013

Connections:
+5VAnalog: C3.1, C5.1, J1.1, U1.7 (V+), U2.1 (VIN), U2.3 (EN)
-5VAnalog: C6.1, J1.3, U1.4 (V-)
ANCSignal: J1.4, R2.2, U1.6
GNDA: C1.2, C3.2, C4.2, C5.2, C6.2, J1.2, MK1.2 (GND), U1.3 (+), U2.2 (GND)
unnamed: C2.2, R1.1
unnamed: C2.1, MK1.1 (OUTPUT)
unnamed: C1.1, C4.1, MK1.3 (VDD), U2.5 (VOUT)
unnamed: R1.2, R2.1, U1.2 (-)

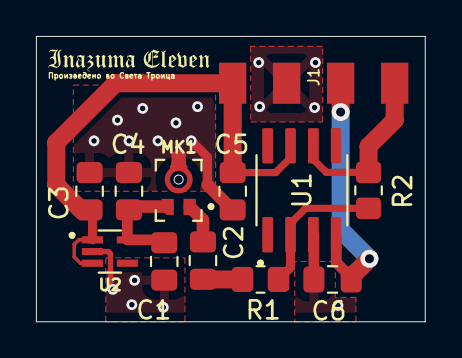
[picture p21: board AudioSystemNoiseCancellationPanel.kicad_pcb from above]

Board: 2 copper layers, 21.6 x 15.9 mm, 12 parts (0 on the bottom side), 8 nets.

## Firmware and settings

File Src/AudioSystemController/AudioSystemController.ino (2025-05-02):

#include <Wire.h>
#include <ESP_I2S.h>
#include <BluetoothA2DPSinkQueued.h>
#include <LiquidCrystal_I2C.h>
//#include "DebugTools.h"


#define I2C_SCL 17
#define I2C_SDA 16

#define I2S_SCK 22
#define I2S_WS 25
#define I2S_SD 26

#define PLAY 19
#define NEXT 18
#define PREV 21

#define AUX_LEFT 34
#define AUX_RIGHT 35

#define LCD_I2C_ADDRESS 0x27
#define LCD_DISPLAY_WIDTH 20
#define DISPLAY_SCROLL_INTERVAL_MS 250

#define BUTTON_DEBOUNCE_DELAY_MS 70

#define BLUETOOTH_DEVICE_NAME "InazumaEleven"

I2SClass i2s;
BluetoothA2DPSinkQueued a2dp_sink(i2s);
LiquidCrystal_I2C lcd(LCD_I2C_ADDRESS, 20, 4);

String currentSongTitle;
String currentSongArtist;
String currentSongAlbum;

esp_avrc_playback_stat_t playbackState;
volatile bool bluetoothEnabled = true;

struct ScrollState 
{
  int scrollIndex = 0;
  unsigned long previousMillis = 0;
};
ScrollState titleScrollState;
ScrollState artistScrollState;
ScrollState albumScrollState;

struct ButtonState 
{
  bool currentState;
  bool lastReading;
  unsigned long lastDebounceTime; 
};
ButtonState playButtonState = {false, false, 0};
ButtonState nextButtonState = {false, false, 0};
ButtonState prevButtonState = {false, false, 0};

void IRAM_ATTR toggleBluetooth()
{
  bluetoothEnabled = !(digitalRead(AUX_LEFT) || digitalRead(AUX_RIGHT));
  if (bluetoothEnabled)
    a2dp_sink.start(BLUETOOTH_DEVICE_NAME);
  else
   a2dp_sink.end();
}

void setup() 
{
  Serial.begin(115200);

  pinMode(AUX_LEFT, INPUT);
  pinMode(AUX_RIGHT, INPUT);
  attachInterrupt(AUX_LEFT, toggleBluetooth, CHANGE);
  attachInterrupt(AUX_RIGHT, toggleBluetooth, CHANGE);

  pinMode(PLAY, INPUT);
  pinMode(NEXT, INPUT);
  pinMode(PREV, INPUT);

  Wire.setPins(I2C_SDA, I2C_SCL);
  lcd.init();                      
  lcd.backlight();

  a2dp_sink.set_avrc_rn_track_change_callback([](uint8_t *id){
    currentSongTitle = "                    ";
    currentSongArtist = "                    ";
    currentSongAlbum = "                    ";
    lcd.clear();
  });
  a2dp_sink.set_avrc_metadata_attribute_mask(ESP_AVRC_MD_ATTR_TITLE | ESP_AVRC_MD_ATTR_ARTIST 
  | ESP_AVRC_MD_ATTR_ALBUM);
  a2dp_sink.set_avrc_metadata_callback([](uint8_t metadata_id, const uint8_t *metadata_value){
    switch (metadata_id) 
    {
      case ESP_AVRC_MD_ATTR_TITLE:
        currentSongTitle = (const char*)metadata_value;
        break;
      case ESP_AVRC_MD_ATTR_ARTIST:
        currentSongArtist = (const char*)metadata_value;
        break;
      case ESP_AVRC_MD_ATTR_ALBUM:
        currentSongAlbum = (const char*)metadata_value;
        break;
      default:
        break;
    }
  });
  a2dp_sink.set_avrc_rn_playstatus_callback([](esp_avrc_playback_stat_t playback_state){
    playbackState = playback_state;
  });
  
  i2s.setPins(I2S_SCK, I2S_WS, I2S_SD);
  i2s.begin(I2S_MODE_STD, 44100, I2S_DATA_BIT_WIDTH_16BIT, I2S_SLOT_MODE_STEREO, I2S_STD_SLOT_BOTH);
  a2dp_sink.start(BLUETOOTH_DEVICE_NAME);
}

void loop() 
{
  if (bluetoothEnabled)
  {
    if (a2dp_sink.is_connected())
    {
      printFormattedSongData();
      if (debounceButton(PLAY, BUTTON_DEBOUNCE_DELAY_MS, playButtonState))
      {
        if (playbackState == ESP_AVRC_PLAYBACK_PLAYING)
          a2dp_sink.pause();
        else if (playbackState == ESP_AVRC_PLAYBACK_PAUSED)
          a2dp_sink.play();
      }
      else if (debounceButton(NEXT, BUTTON_DEBOUNCE_DELAY_MS, nextButtonState))
        a2dp_sink.next();
      else if (debounceButton(PREV, BUTTON_DEBOUNCE_DELAY_MS, prevButtonState))
        a2dp_sink.previous();
    }
    else
    {   
      lcd.clear();
      lcd.setCursor(0, 0);
      lcd.print("Bluetooth ON");
      lcd.setCursor(0, 1);
      lcd.print("Not connected");
    }
  }
  else
  {
    lcd.clear();
    lcd.setCursor(0, 0);
    lcd.print("Bluetooth OFF");
  }
}

bool debounceButton(uint8_t buttonPin, unsigned long debounceDelay, ButtonState &state) 
{
  bool reading = digitalRead(buttonPin);
  if (reading != state.lastReading)
    state.lastDebounceTime = millis();

  if ((millis() - state.lastDebounceTime) > debounceDelay)
    if (reading != state.currentState)
      state.currentState = reading;

  state.lastReading = reading;
  return state.currentState;
}

String repeatString(String text, int times) 
{
  String result = "";
  for (int i = 0; i < times; i++)
    result += text;
  return result;
}

void displayStaticAndScrollData(String dataText, int row, int displayWidth, int interval, ScrollState &state) 
{
  if (dataText.length() > displayWidth) 
  {
    dataText += "  ";
    unsigned long currentMillis = millis();
    if (currentMillis - state.previousMillis >= interval) 
    {
      state.previousMillis = currentMillis;

      lcd.setCursor(0, row);
      lcd.print(repeatString(" ", displayWidth));

      String displayText;
      if (state.scrollIndex + displayWidth <= dataText.length())
        displayText = dataText.substring(state.scrollIndex, state.scrollIndex + displayWidth);
      else
        displayText = dataText.substring(state.scrollIndex) + dataText.substring(0, (state.scrollIndex + displayWidth) % dataText.length());

      lcd.setCursor(0, row);
      lcd.print(displayText);

      state.scrollIndex = (state.scrollIndex + 1) % dataText.length();
    }
  } 
  else 
  {
    lcd.setCursor(0, row);
    lcd.print(dataText);
  }
}

void printFormattedSongData()
{
  displayStaticAndScrollData(currentSongTitle, 0, LCD_DISPLAY_WIDTH, DISPLAY_SCROLL_INTERVAL_MS, titleScrollState);
  displayStaticAndScrollData(currentSongArtist, 1, LCD_DISPLAY_WIDTH, DISPLAY_SCROLL_INTERVAL_MS, artistScrollState);
  displayStaticAndScrollData(currentSongAlbum, 2, LCD_DISPLAY_WIDTH, DISPLAY_SCROLL_INTERVAL_MS, albumScrollState);
}

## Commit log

2024-10-14 add kicad main panel schematic
    [AudioSystemMainPanel.kicad_pcb, AudioSystemMainPanel.kicad_sch]
2024-10-14 gitignore working
    [AudioSystemMainPanel.kicad_sch]
2024-10-17 added filter/eq panel, small fixes for main panel
    [AudioSystemEQPanel.kicad_pcb, AudioSystemEQPanel.kicad_sch, AudioSystemMainPanel.kicad_sch]
2024-10-17 created noise cancellation panel, added a custom symbol library to project
    [AudioSystemMainPanel.kicad_sch, AudioSystemNoiseCancellationPanel.kicad_pcb, AudioSystemNoiseCancellationPanel.kicad_sch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]
2024-10-17 fixed symbol lab problem, added symbols to all ics
    [AudioSystemEQPanel.kicad_sch, AudioSystemMainPanel.kicad_sch]
2024-10-22 changed all panels input and output audio interfaces, added noisecancellation panel
    [AudioSystemEQPanel.kicad_sch, AudioSystemMainPanel.kicad_sch, AudioSystemNoiseCancellationPanel.kicad_sch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]
2024-10-31 added code debug function namespace, fixed eq-panel resistor values
    [AudioSystemEQPanel.kicad_pcb, AudioSystemEQPanel.kicad_sch, AudioSystemMainPanel.kicad_pcb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]
2024-11-06 added full audio system schematic (not completed)
    [AudioSystemEQPanel.kicad_sch, AudioSystemFull.kicad_pcb, AudioSystemFull.kicad_sch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]
2024-11-13 a2dp sink, avrcp data displaying and animating on lcd done
    [AudioSystemFull.kicad_sch]
2024-11-18 progress check
    [AudioSystemFull.kicad_sch, AudioSystemNoiseCancellationPanel.kicad_sch, LM1085IT-3.3.step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]
2024-11-18 deleted unnecessary schematics
    [AudioSystemEQPanel.kicad_pcb, AudioSystemEQPanel.kicad_sch, AudioSystemMainPanel.kicad_pcb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]
2024-12-11 power supply schematic possibly done
    [AudioSystemFull.kicad_sch, AudioSystemNoiseCancellationPanel.kicad_sch, LMR51420XFDDCR.step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]
2024-12-16 complete head unit schematic
    [AudioSystemFull.kicad_sch, AudioSystemNoiseCancellationPanel.kicad_sch]
2024-12-21 added next/play/prev buttons (hardware and software)
    [AudioSystemFull.kicad_sch]
2024-12-24 added all resistor footprints
    [AudioSystemFull.kicad_pcb, AudioSystemFull.kicad_sch]
2024-12-26 added capacitor footprints and all known elements serial numbers
    [AudioSystemFull.kicad_sch]
2024-12-27 added all footprints
    [AudioSystemFull.kicad_sch]
2024-12-28 organize footprints by purpose
    [AudioSystemFull.kicad_pcb, AudioSystemFull.kicad_sch]
2025-01-04 footprint placement part 1
    [AudioSystemFull.kicad_pcb, AudioSystemFull.kicad_sch]
2025-01-13 footprint placement possibly done, minor schematic changes
    [AudioSystemFull.kicad_pcb, AudioSystemFull.kicad_sch, MIC39100-5.0WS.step]
2025-01-18 progress sync
    [AudioSystemFull.kicad_pcb, AudioSystemFull.kicad_sch]
2025-02-05 pcbs done
    [AudioSystemFull.kicad_pcb, AudioSystemFull.kicad_sch, AudioSystemNoiseCancellationPanel.kicad_pcb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]
2025-02-05 add mounting holes to main pcb
    [AudioSystemFull.kicad_pcb, AudioSystemFull.kicad_sch, AudioSystemNoiseCancellationPanel.kicad_pcb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]
2025-02-05 3dmodel changes
    [AudioSystemFull.kicad_pcb]
2025-03-11 sync latest
    [AudioSystemFull.kicad_pcb, AudioSystemNoiseCancellationPanel.kicad_pcb]
2025-05-02 button debounce fix, minor changes
    [AudioSystemController.ino]
